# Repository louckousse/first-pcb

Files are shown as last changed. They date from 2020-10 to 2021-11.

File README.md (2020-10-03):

# FLATBRAIN
My first PCB, inspired by the Kyria from [Splitkb](https://splitkb.com) and the [Atreus](https://github.com/technomancy/atreus).
The goal is to get an unsplitted Kyria easily transportable.
The angle is 28° which approximatively correspond to my hand angle.

All the pcb files are created in Kicad, you can find everything in the root folder.

All the dxf files are created in Freecad, you can find everything in the case folder.
For now there is only file necessary to create pcb plate, and the kicad project associated.

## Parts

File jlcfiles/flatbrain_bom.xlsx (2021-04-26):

Comment | Designator | Footprint | LCSC Part #（optional）
Diodes | D29,D1,D2,D3,D4,D5,D6,D7,D8,D9,D10,D11,D12,D13,D14,D15,D16,D17,D18,D19,D20,D21,D22,D23,D24,D25,D39,D38,D37,D28,D32,D33,D34,D35,D26,D36,D30,D27 | Diode-Hybrid-Back | C2099
Reset | RST1 | SKQG-1155865 | C318884
5.1k | R6,R5 | R_0805_2012Metric | C27834
Ferrite_Bead_Small | FB1 | L_0805_2012Metric_Pad1.15x1.40mm_HandSolder | C18305
0.1uF | C8,C4,C3,C2 | C_0805_2012Metric | C49678
PRTR5V0U2X | U2 | SOT143B | C78442
ATmega32U4-AU | U1 | QFN-44-1EP_7x7mm_P0.5mm_EP5.2x5.2mm | C44854
22pF | C7,C6 | C_0805_2012Metric | C1804
16MHz | Y1 | Crystal_SMD_3225-4Pin_3.2x2.5mm | C164044
10k | R4,R1 | R_0805_2012Metric | C17414
22 | R3,R2 | R_0805_2012Metric | C17561
500mA | F1 | Fuse_1206_3216Metric | C163133
10uF | C5 | C_0805_2012Metric | C15850
1uF | C1 | C_0805_2012Metric | C28323
USB | USB1 | USB_C_Receptacle_HRO_TYPE-C-31-M-12 | C165948

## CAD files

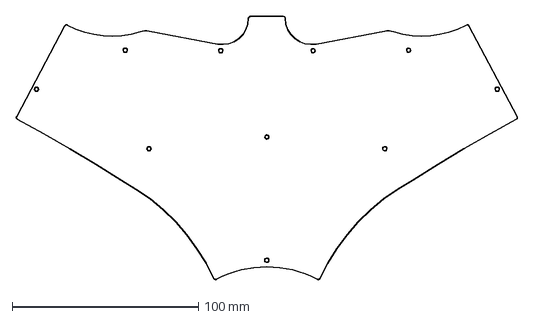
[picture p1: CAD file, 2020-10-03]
case/bottom/bottom.dxf
268.9 x 141.1 mm

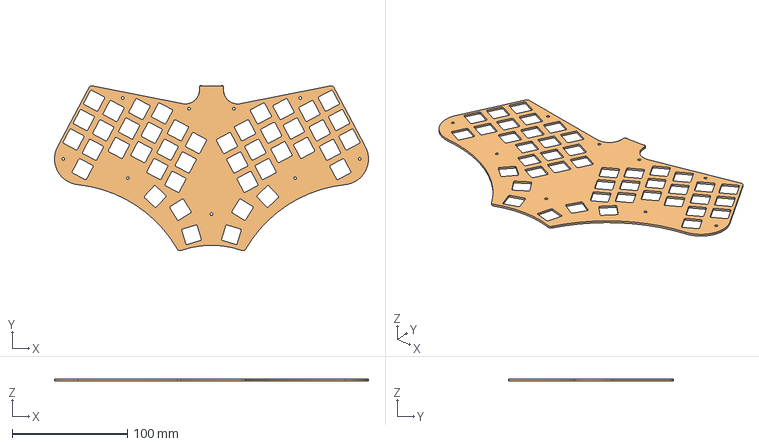
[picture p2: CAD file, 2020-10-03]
case/flatbrain.FCStd
272.2 x 143.4 x 1.60 mm
Body-plate-pcb
Body-plate

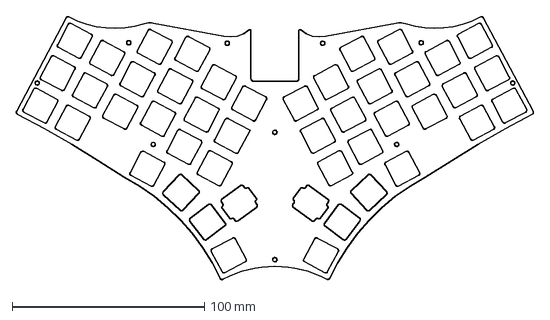
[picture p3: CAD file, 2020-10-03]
case/plate/plate.dxf
268.9 x 136.7 mm

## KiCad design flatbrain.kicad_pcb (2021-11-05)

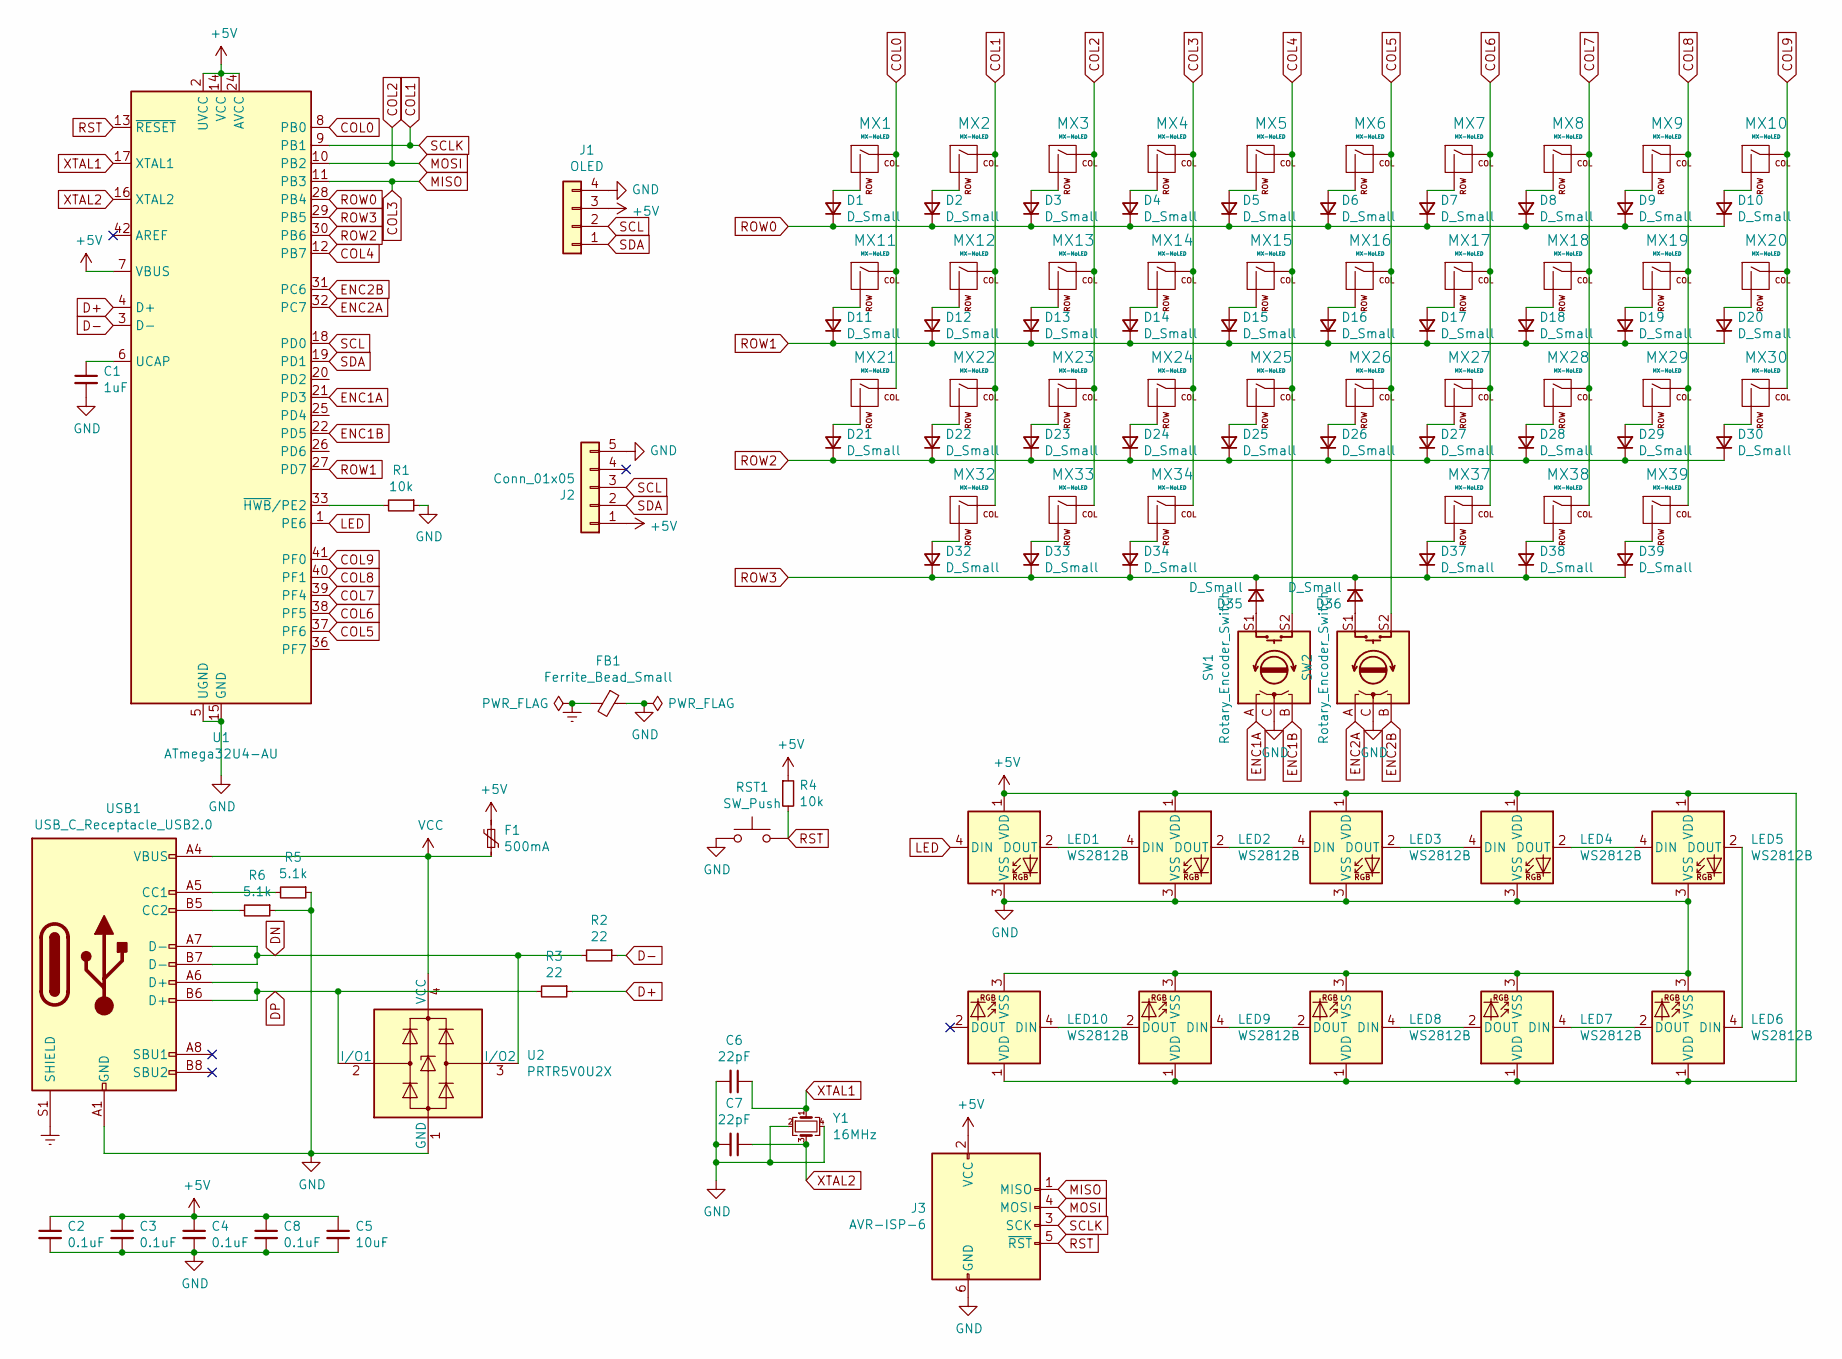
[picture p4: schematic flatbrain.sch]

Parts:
C1: 1uF; C_0805_2012Metric
C2, C3, C4, C8: 0.1uF; C_0805_2012Metric
C5: 10uF; C_0805_2012Metric
C6, C7: 22pF; C_0805_2012Metric
D1, D2, D3, D4, D5, D6, D7, D8, D9, D10, D11, D12, D13, D14, D15, D16, D17, D18, D19, D20, D21, D22, D23, D24, D25, D26, D27, D28, D29, D30, D32, D33, D34, D35, D36, D37, D38, D39: D_Small; Diode-Hybrid-Back
F1: 500mA; Fuse_1206_3216Metric
FB1: Ferrite_Bead_Small; L_0805_2012Metric_Pad1.15x1.40mm_HandSolder
J1: OLED; PinHeader_1x04_P2.54mm_Vertical
J2: Conn_01x05; pimoroni_trackball
J3: AVR-ISP-6; Reset_Pretty-Mask
LED1, LED2, LED3, LED4, LED5, LED6, LED7, LED8, LED9, LED10: WS2812B; LED_WS2812B_PLCC4_5.0x5.0mm_P3.2mm
MX1, MX2, MX3, MX4, MX5, MX6, MX7, MX8, MX9, MX10, MX11, MX12, MX13, MX14, MX15, MX16, MX17, MX18, MX19, MX20, MX21, MX22, MX23, MX24, MX25, MX26, MX27, MX28, MX29, MX30, MX32, MX33, MX34, MX37, MX38, MX39: MX-NoLED; mix_1u
R1, R4: 10k; R_0805_2012Metric
R2, R3: 22; R_0805_2012Metric
R5, R6: 5.1k; R_0805_2012Metric
RST1: SW_Push; SKQG-1155865
SW1, SW2: Rotary_Encoder_Switch; rotary_full
U1: ATmega32U4-AU; TQFP-44_10x10mm_P0.8mm
U2: PRTR5V0U2X; SOT143B
USB1: USB_C_Receptacle_USB2.0; USB_C_Receptacle_HRO_TYPE-C-31-M-12
Y1: 16MHz; Crystal_SMD_3225-4Pin_3.2x2.5mm

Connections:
+5V: C2.1, C3.1, C4.1, C5.1, C8.1, F1.1, J1.3, J2.1, J3.2 (VCC), LED1.1 (VDD), LED2.1 (VDD), LED3.1 (VDD), LED4.1 (VDD), LED5.1 (VDD), LED6.1 (VDD), LED7.1 (VDD), LED8.1 (VDD), LED9.1 (VDD), LED10.1 (VDD), R4.1, U1.2 (UVCC), U1.7 (VBUS), U1.14 (VCC), U1.24 (AVCC), U1.34 (VCC), U1.44 (AVCC); also elsewhere on the board
COL0: MX1.1 (COL), MX11.1 (COL), MX21.1 (COL), U1.8 (PB0)
COL1: J3.3 (SCK), MX2.1 (COL), MX12.1 (COL), MX22.1 (COL), MX32.1 (COL), U1.9 (PB1)
COL2: J3.4 (MOSI), MX3.1 (COL), MX13.1 (COL), MX23.1 (COL), MX33.1 (COL), U1.10 (PB2)
COL3: J3.1 (MISO), MX4.1 (COL), MX14.1 (COL), MX24.1 (COL), MX34.1 (COL), U1.11 (PB3)
COL4: MX5.1 (COL), MX15.1 (COL), MX25.1 (COL), SW1.S2, U1.12 (PB7)
COL5: MX6.1 (COL), MX16.1 (COL), MX26.1 (COL), SW2.S2, U1.37 (PF6)
COL6: MX7.1 (COL), MX17.1 (COL), MX27.1 (COL), MX37.1 (COL), U1.38 (PF5)
COL7: MX8.1 (COL), MX18.1 (COL), MX28.1 (COL), MX38.1 (COL), U1.39 (PF4)
COL8: MX9.1 (COL), MX19.1 (COL), MX29.1 (COL), MX39.1 (COL), U1.40 (PF1)
COL9: MX10.1 (COL), MX20.1 (COL), MX30.1 (COL), U1.41 (PF0)
D+: R3.1, U1.4 (D+)
D-: R2.1, U1.3 (D-)
DN: R2.2, U2.3 (I/O2), USB1.A7 (D-), USB1.B7 (D-)
DP: R3.2, U2.2 (I/O1), USB1.A6 (D+), USB1.B6 (D+)
ENC1A: SW1.A, U1.21 (PD3)
ENC1B: SW1.B, U1.22 (PD5)
ENC2A: SW2.A, U1.32 (PC7)
ENC2B: SW2.B, U1.31 (PC6)
Earth: FB1.2, USB1.S1 (SHIELD)
GND: C1.2, C2.2, C3.2, C4.2, C5.2, C6.2, C7.2, C8.2, FB1.1, J1.4, J2.5, J3.6 (GND), LED1.3 (VSS), LED2.3 (VSS), LED3.3 (VSS), LED4.3 (VSS), LED5.3 (VSS), LED6.3 (VSS), LED7.3 (VSS), LED8.3 (VSS), LED9.3 (VSS), LED10.3 (VSS), R1.1, R5.1, R6.1, RST1.1, SW1.C, SW2.C, U1.5 (UGND), U1.15 (GND), U1.23 (GND), U1.35 (GND), U1.43 (GND), U2.1 (GND), USB1.A1 (GND), USB1.A12 (GND), USB1.B1 (GND), USB1.B12 (GND), Y1.2, Y1.4; also elsewhere on the board
LED: LED1.4 (DIN), U1.1 (PE6)
unnamed: C1.1, U1.6 (UCAP)
unnamed: D1.2 (A), MX1.2 (ROW)
unnamed: D2.2 (A), MX2.2 (ROW)
unnamed: D3.2 (A), MX3.2 (ROW)
unnamed: D4.2 (A), MX4.2 (ROW)
unnamed: D5.2 (A), MX5.2 (ROW)
unnamed: D6.2 (A), MX6.2 (ROW)
unnamed: D7.2 (A), MX7.2 (ROW)
unnamed: D8.2 (A), MX8.2 (ROW)
unnamed: D9.2 (A), MX9.2 (ROW)
unnamed: D10.2 (A), MX10.2 (ROW)
unnamed: D11.2 (A), MX11.2 (ROW)
unnamed: D12.2 (A), MX12.2 (ROW)
unnamed: D13.2 (A), MX13.2 (ROW)
unnamed: D14.2 (A), MX14.2 (ROW)
unnamed: D15.2 (A), MX15.2 (ROW)
unnamed: D16.2 (A), MX16.2 (ROW)
unnamed: D17.2 (A), MX17.2 (ROW)
unnamed: D18.2 (A), MX18.2 (ROW)
unnamed: D19.2 (A), MX19.2 (ROW)
unnamed: D20.2 (A), MX20.2 (ROW)
unnamed: D21.2 (A), MX21.2 (ROW)
unnamed: D22.2 (A), MX22.2 (ROW)
unnamed: D23.2 (A), MX23.2 (ROW)
unnamed: D24.2 (A), MX24.2 (ROW)
unnamed: D25.2 (A), MX25.2 (ROW)
unnamed: D26.2 (A), MX26.2 (ROW)
unnamed: D27.2 (A), MX27.2 (ROW)
unnamed: D28.2 (A), MX28.2 (ROW)
unnamed: D29.2 (A), MX29.2 (ROW)
unnamed: D30.2 (A), MX30.2 (ROW)
unnamed: D32.2 (A), MX32.2 (ROW)
unnamed: D33.2 (A), MX33.2 (ROW)
unnamed: D34.2 (A), MX34.2 (ROW)
unnamed: D35.2 (A), SW1.S1
unnamed: D36.2 (A), SW2.S1
unnamed: D37.2 (A), MX37.2 (ROW)
unnamed: D38.2 (A), MX38.2 (ROW)
unnamed: D39.2 (A), MX39.2 (ROW)
unnamed: LED1.2 (DOUT), LED2.4 (DIN)
unnamed: LED2.2 (DOUT), LED3.4 (DIN)
unnamed: LED3.2 (DOUT), LED4.4 (DIN)
unnamed: LED4.2 (DOUT), LED5.4 (DIN)
unnamed: LED5.2 (DOUT), LED6.4 (DIN)
unnamed: LED6.2 (DOUT), LED7.4 (DIN)
unnamed: LED7.2 (DOUT), LED8.4 (DIN)
unnamed: LED8.2 (DOUT), LED9.4 (DIN)
unnamed: LED9.2 (DOUT), LED10.4 (DIN)
unnamed: R1.2, U1.33 (~HWB~/PE2)
unnamed: R5.2, USB1.A5 (CC1)
unnamed: R6.2, USB1.B5 (CC2)
ROW0: D1.1 (K), D2.1 (K), D3.1 (K), D4.1 (K), D5.1 (K), D6.1 (K), D7.1 (K), D8.1 (K), D9.1 (K), D10.1 (K), U1.28 (PB4)
ROW1: D11.1 (K), D12.1 (K), D13.1 (K), D14.1 (K), D15.1 (K), D16.1 (K), D17.1 (K), D18.1 (K), D19.1 (K), D20.1 (K), U1.27 (PD7)
ROW2: D21.1 (K), D22.1 (K), D23.1 (K), D24.1 (K), D25.1 (K), D26.1 (K), D27.1 (K), D28.1 (K), D29.1 (K), D30.1 (K), U1.30 (PB6)
ROW3: D32.1 (K), D33.1 (K), D34.1 (K), D35.1 (K), D36.1 (K), D37.1 (K), D38.1 (K), D39.1 (K), U1.29 (PB5)
RST: J3.5 (~RST), R4.2, RST1.2, U1.13 (~RESET)
SCL: J1.2, J2.3, U1.18 (PD0); also elsewhere on the board
SDA: J1.1, J2.2, U1.19 (PD1); also elsewhere on the board
VCC: F1.2, U2.4 (VCC), USB1.A4 (VBUS), USB1.A9 (VBUS), USB1.B4 (VBUS), USB1.B9 (VBUS)
XTAL1: C6.1, U1.17 (XTAL1), Y1.1
XTAL2: C7.1, U1.16 (XTAL2), Y1.3

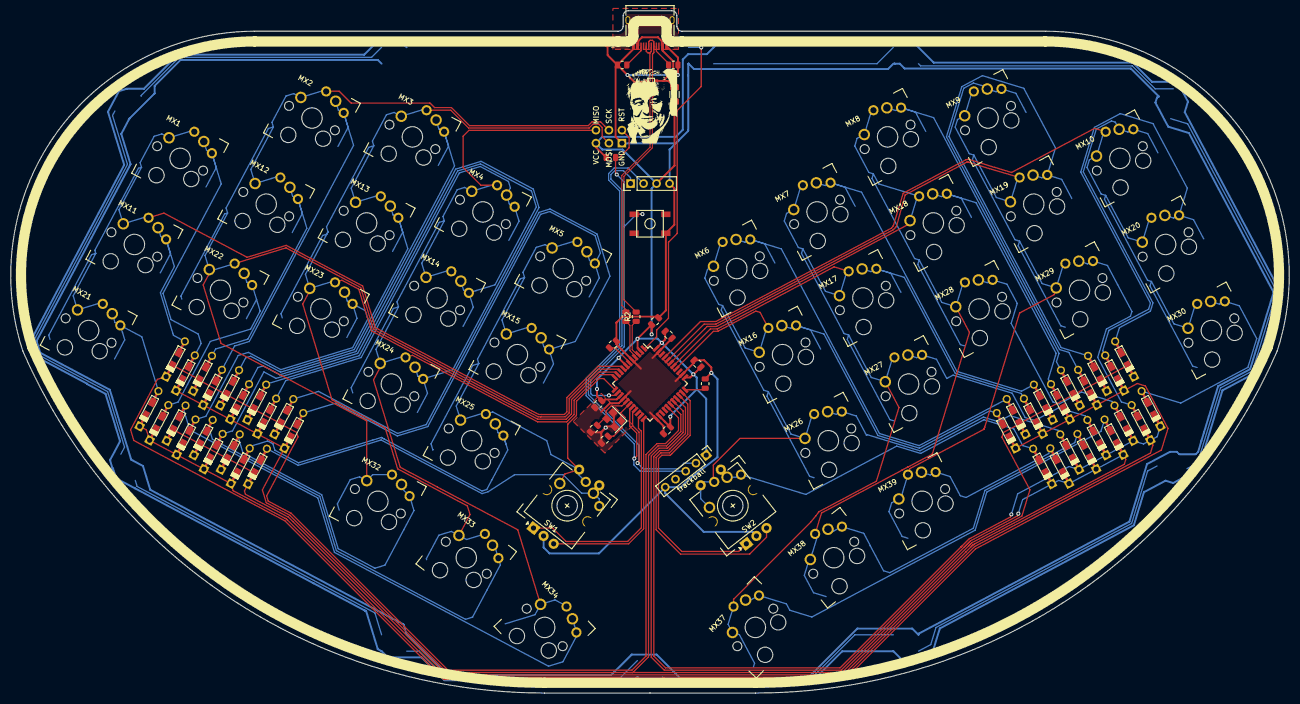
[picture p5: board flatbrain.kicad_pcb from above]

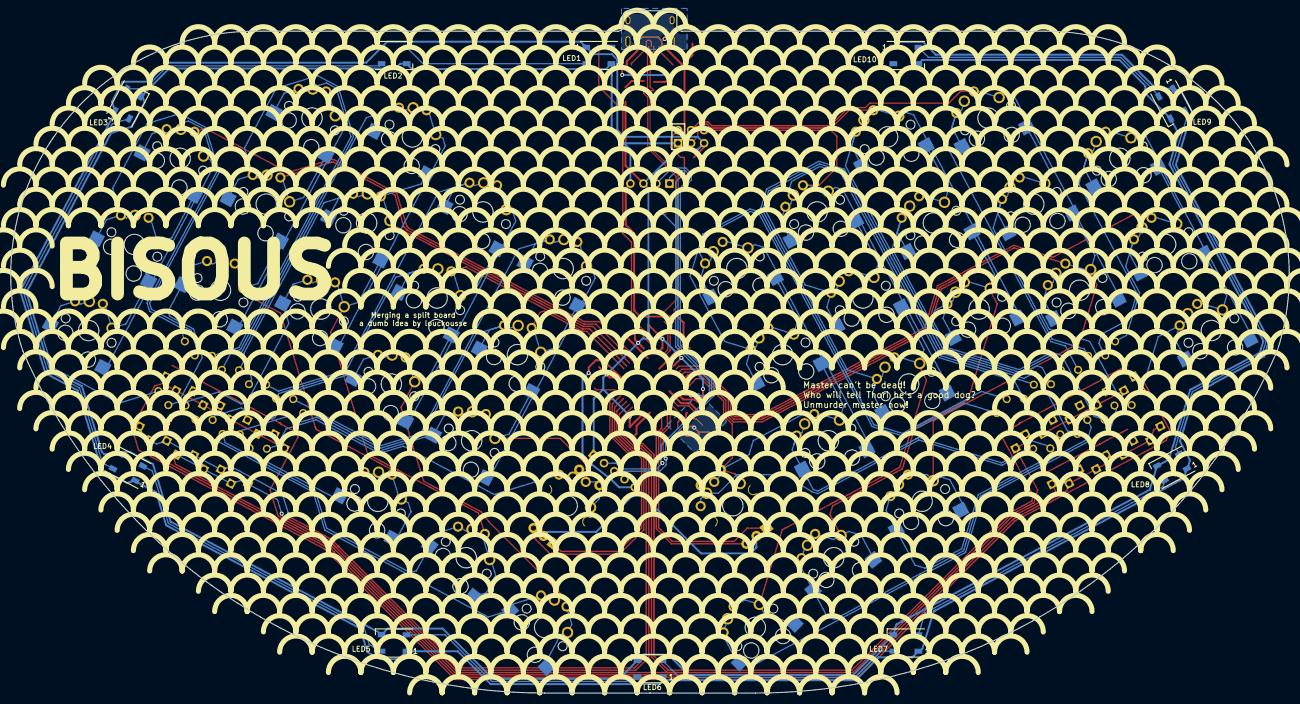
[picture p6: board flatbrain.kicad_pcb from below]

Board: 2 copper layers, 249.8 x 133.3 mm, 110 parts (49 on the bottom side), 83 nets.

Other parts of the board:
trackball: Conn_01x05; pimoroni_trackball

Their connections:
+5V: trackball.1; also elsewhere on the board
GND: trackball.5; also elsewhere on the board
SCL: trackball.3; also elsewhere on the board
SDA: trackball.2; also elsewhere on the board

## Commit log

2020-04-04 Init project
    [first-pcb.kicad_pcb, first-pcb.sch]
2020-04-04 Add the MCU
    [first-pcb.sch]
2020-04-05 Electronic schematic is over
    [first-pcb.sch]
2020-04-05 My very first pcb is over
    [first-pcb.sch]
2020-04-14 First revision (#1)
    First design includes 44 switch, 44 smd diodes, 1 pro-micro, 1 4-pin header for oled screen,
    outline and mounting points
    * V0.0.1 of the flatbrain keyboard
    * Replace 1u in thumb by 1.75 and 1.5
    * Perfect alignement
    * routing corrected
    * realign + outline
    * add contour.dxf
    * final design
    * first revision is over
    [contour.dxf, first-pcb.kicad_pcb, first-pcb.sch]
2020-04-19 Version 0.1.1 (#2)
    * New routing to use less pin
    * Add LED on the schema
    * Routing the LED
    * Change the silks to display switch info
    * add the plate dxf file
    * Rename contour in bottom
    [bottom.dxf, first-pcb.kicad_pcb, first-pcb.sch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]
2020-10-03 V0.2.0 (#3)
    * Replace smd diode with hybrid
    * Move all files between two folder
    PCB: contains everything pcb related
    CASE: contains everythind dxf related or non electronical
    * Correct the size of the switch hole
    * Move pcb folder to get kicad import working with submodul
    * update cache
    * Update mx footprints
    TODO
    * verify the diode placement
    * replace right 1.75u with 1u + encoder
    * diode placement
    * Correct leds connection
    * Move lowest pinky keys to thumb cluster
    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
    [bottom.dxf, bottom.kicad_pcb, first-pcb.kicad_pcb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]
2021-01-10 wip: switches placed, matrix change
    [flatbrain.kicad_pcb, flatbrain.sch]
2021-01-13 update schema
    [flatbrain.sch]
2021-01-13 everything is placed
    [flatbrain.kicad_pcb]
2021-01-14 first half done
    [flatbrain.kicad_pcb]
2021-01-14 all route done
    [flatbrain.kicad_pcb, flatbrain.sch]
2021-01-14 update footprint
2021-01-23 rev3 is done
    add a rotary
    add silk
    [flatbrain.kicad_pcb, flatbrain.sch]
2021-01-24 some more silk
    [flatbrain.kicad_pcb]
2021-02-06 move diode 1.5mm
    [flatbrain.kicad_pcb]
2021-03-06 half pcba
    [flatbrain.kicad_pcb, flatbrain.sch]
2021-03-12 pcba over
    [flatbrain.kicad_pcb, flatbrain.sch]
2021-03-16 edge cuts
    [flatbrain.kicad_pcb]
2021-04-26 ready to prod
    [flatbrain.kicad_pcb, flatbrain.sch, flatbrain_bom.xlsx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]
2021-10-26 move thumb cluster
    [flatbrain.kicad_pcb]
